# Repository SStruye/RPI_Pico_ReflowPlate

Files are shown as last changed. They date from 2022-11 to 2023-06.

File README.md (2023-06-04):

# PICO Reflow Plate v1
PICO Reflow Plate is a diy reflow plate based around a raspberry PI pico. The user is capable of adjusting the settings of the reflow curve like, preheat temperature, soak time, reflow temperature en reflow time.
## Usage:
- After  turning on the power the start menu will appear on the screen. 
- Selecting the setup menu will take you to the different adjustable parameters.
- After adjusting the parameters go back to the start menu en press start reflow. This will start te process.
- The current temperature, elapsed time and current state will be displayed on the screen during the reflow process.
- After the reflowing is done, the plate will go in to cooldown mode until the plate is below 50 degrees.

## Build:
### Hardware:
As casing I repurposed an old broken DC power supply.

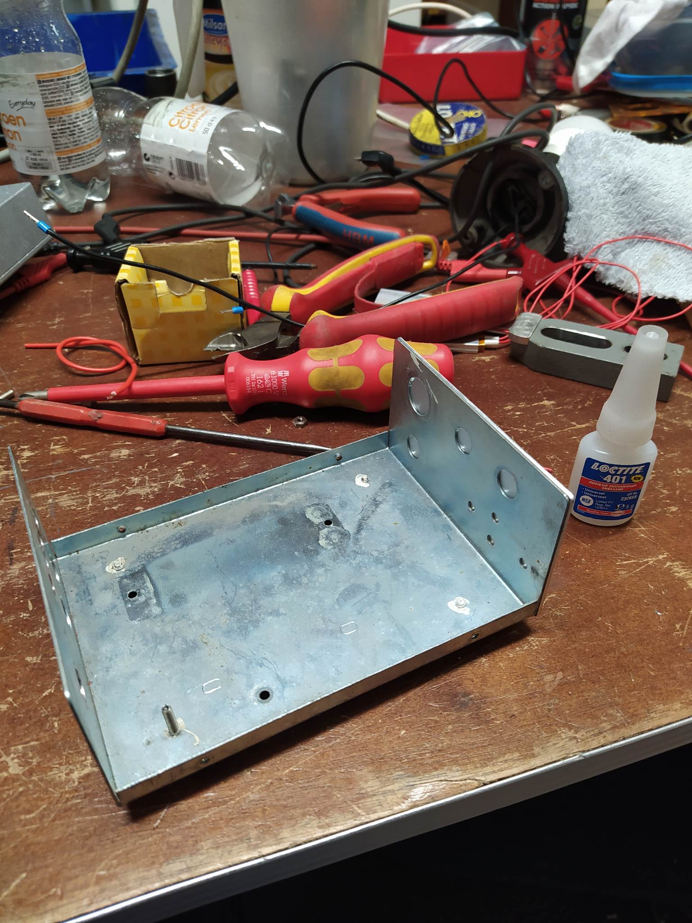
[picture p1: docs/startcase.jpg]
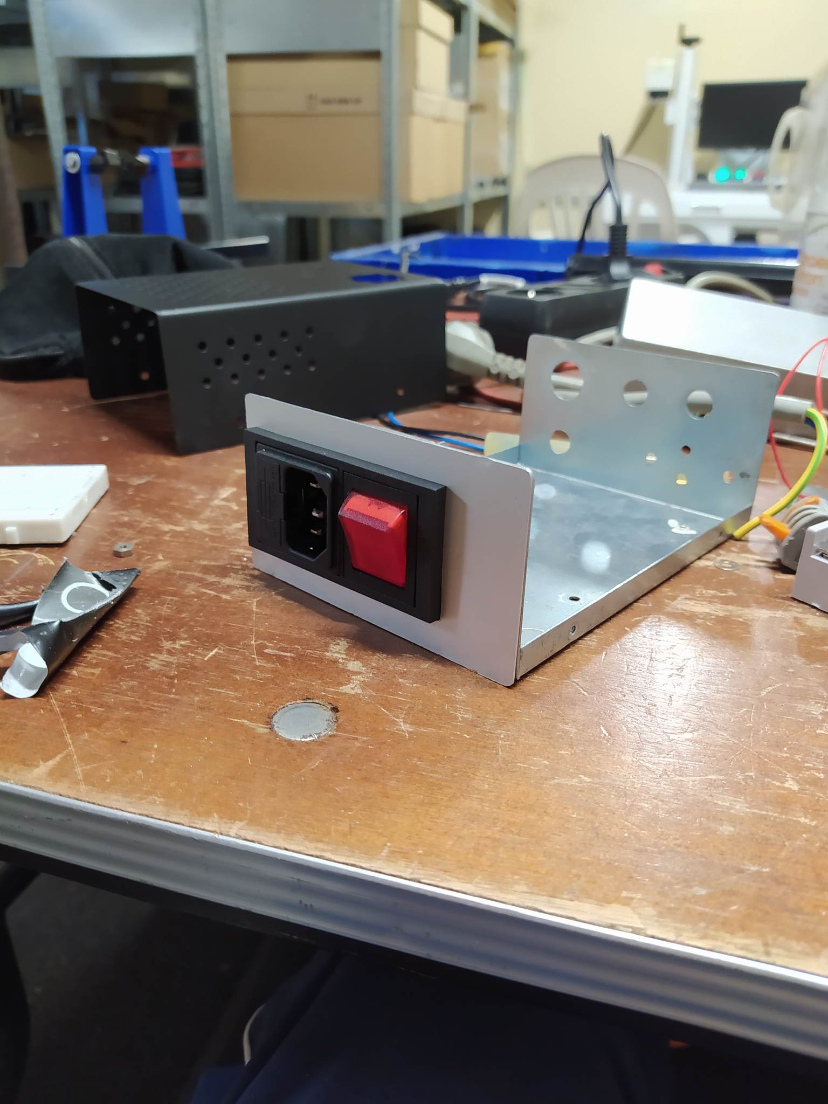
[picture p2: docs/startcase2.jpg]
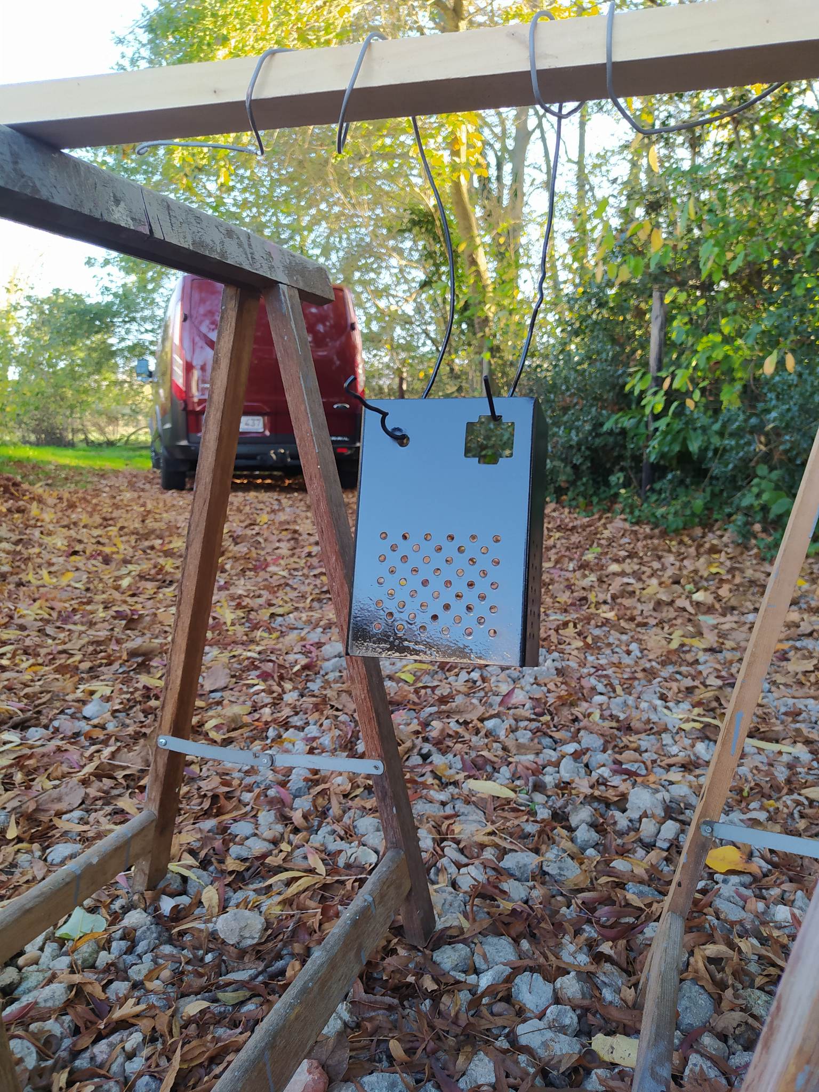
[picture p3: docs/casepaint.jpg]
  

As plate I used an 1590BB hammond enclosure where I used aluminum tape to position the NTC sensors, thermal paste to asure good thermal transfer and high heat silicone to keep everything in place.

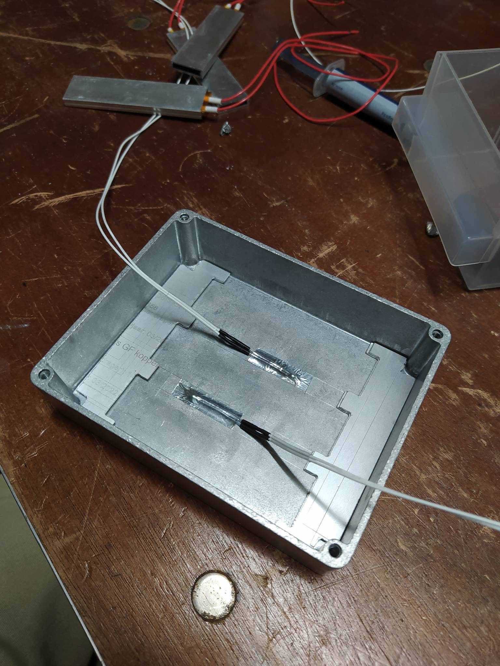
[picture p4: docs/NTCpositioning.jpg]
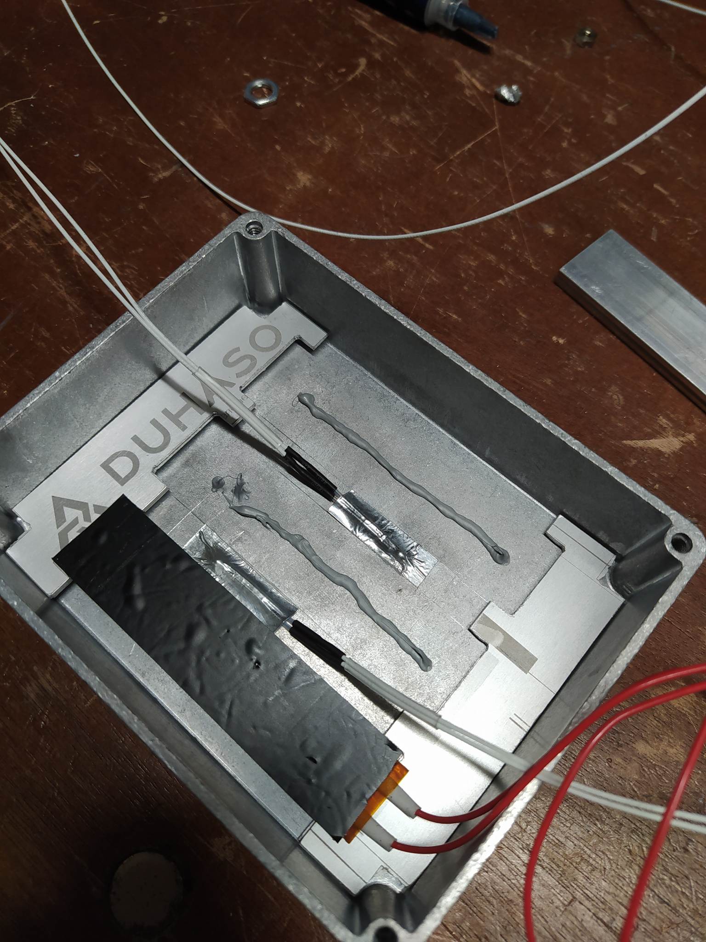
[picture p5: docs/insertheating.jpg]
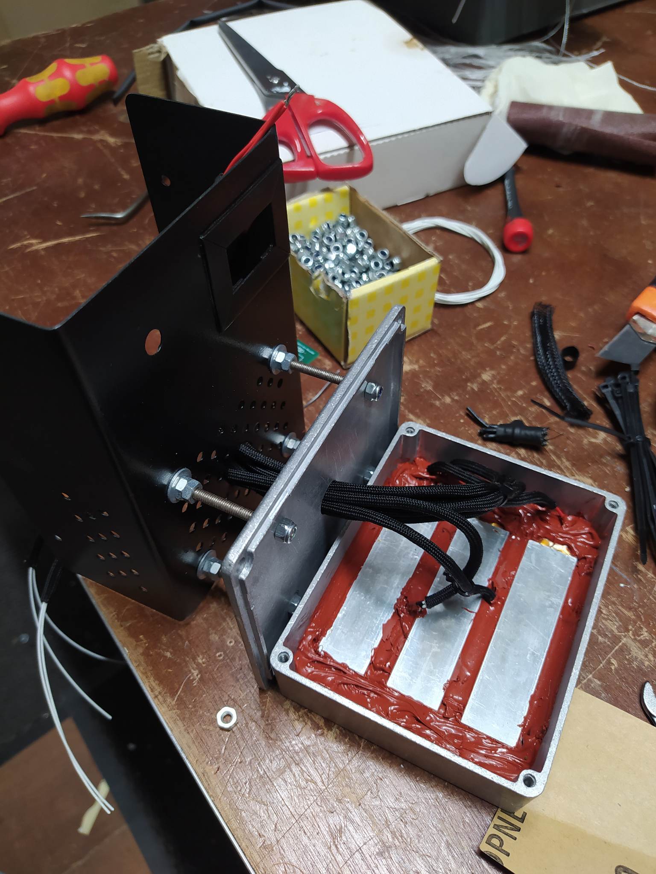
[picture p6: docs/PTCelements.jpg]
  

For ease of use, I made a pin distribution board for the PICO wich also holds the resistors for the led and the thermistors. The PCB was lasered on a fiber laser.

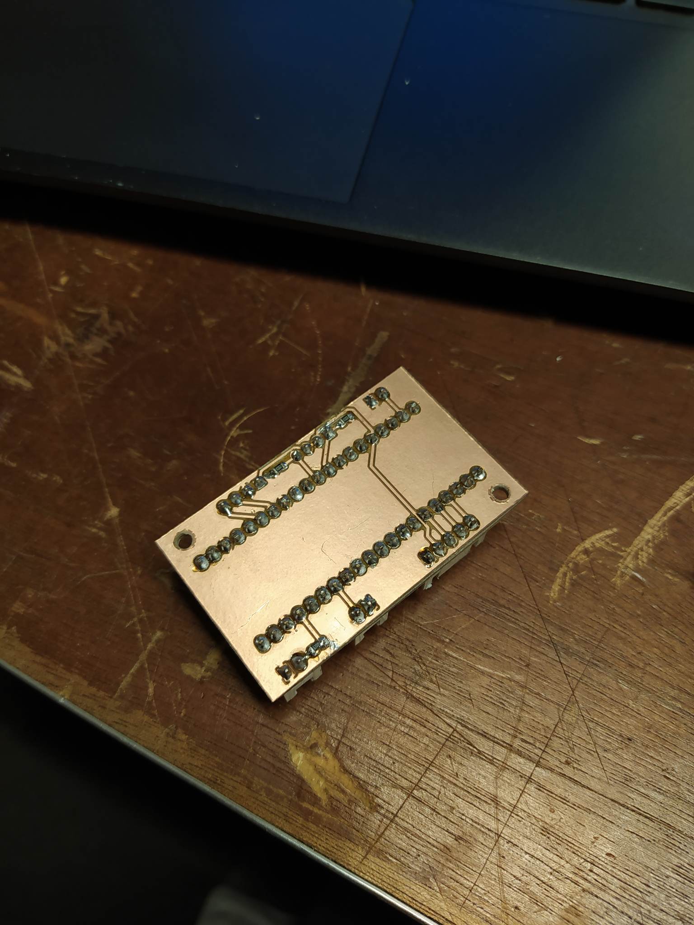
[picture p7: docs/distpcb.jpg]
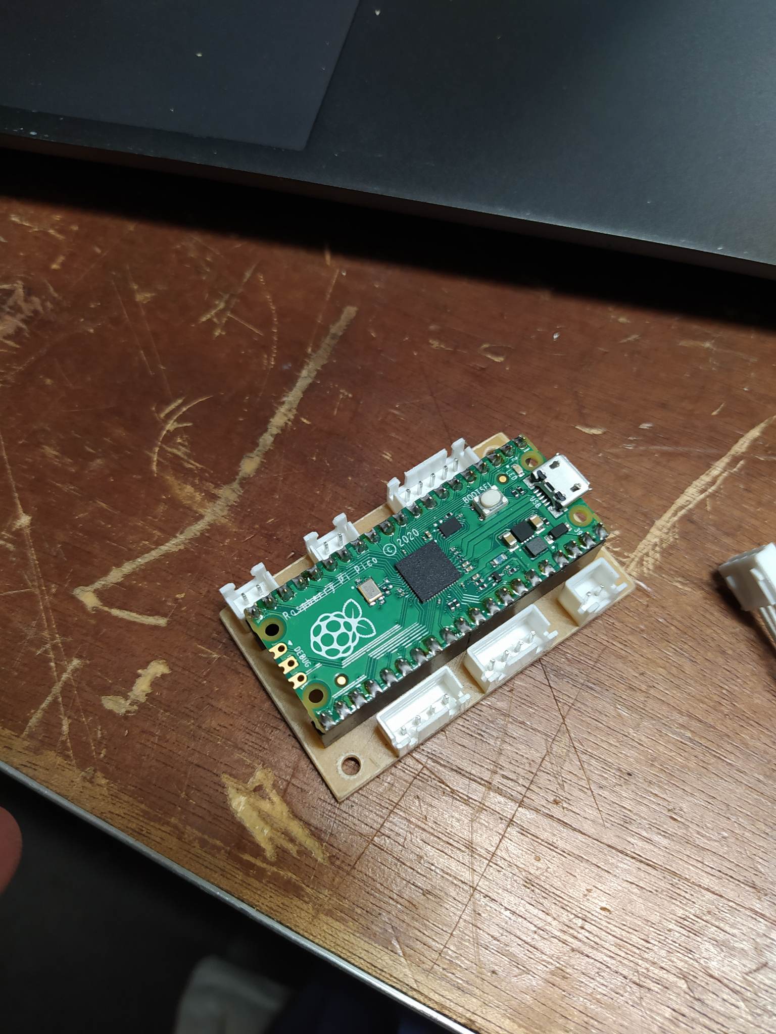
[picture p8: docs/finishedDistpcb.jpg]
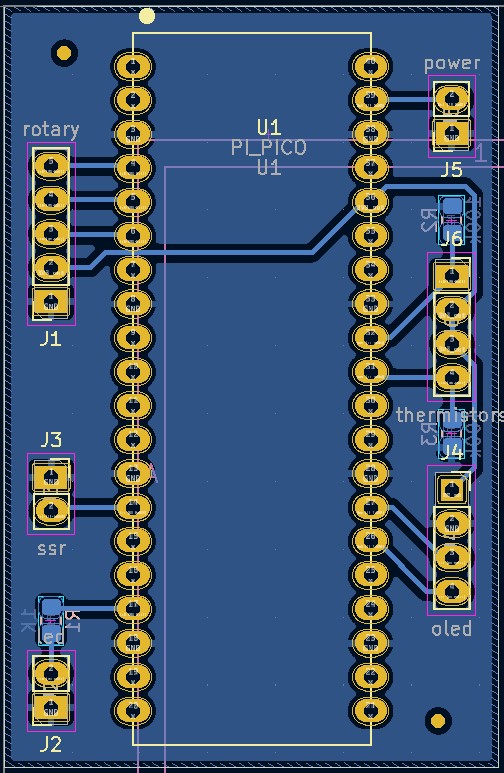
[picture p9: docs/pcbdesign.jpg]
  

Furthermore a solidstate relay is used to control the PTC elements, a 230V to 3.3V buck converter is used to power the PICO and an LED is added indicating when the hotplate is too hot too touch.
As user interface a SSD1306 display and a KY-040 rotary encoder with push button is used.

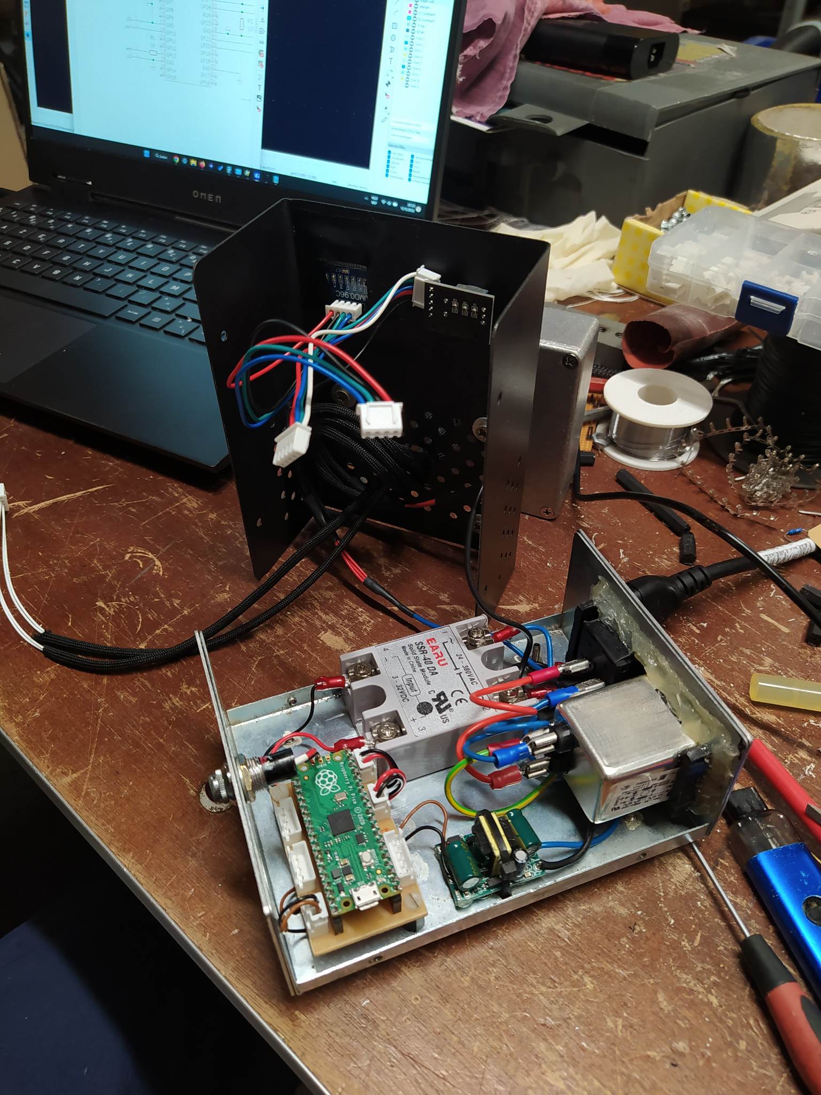
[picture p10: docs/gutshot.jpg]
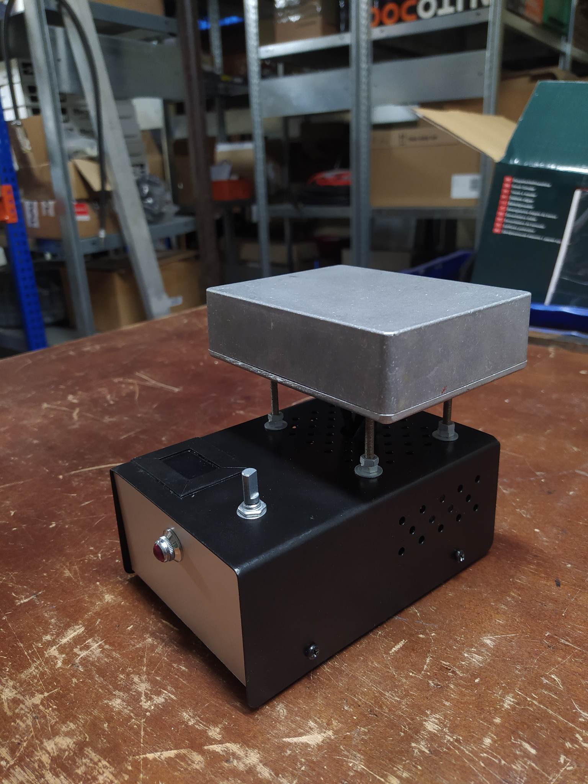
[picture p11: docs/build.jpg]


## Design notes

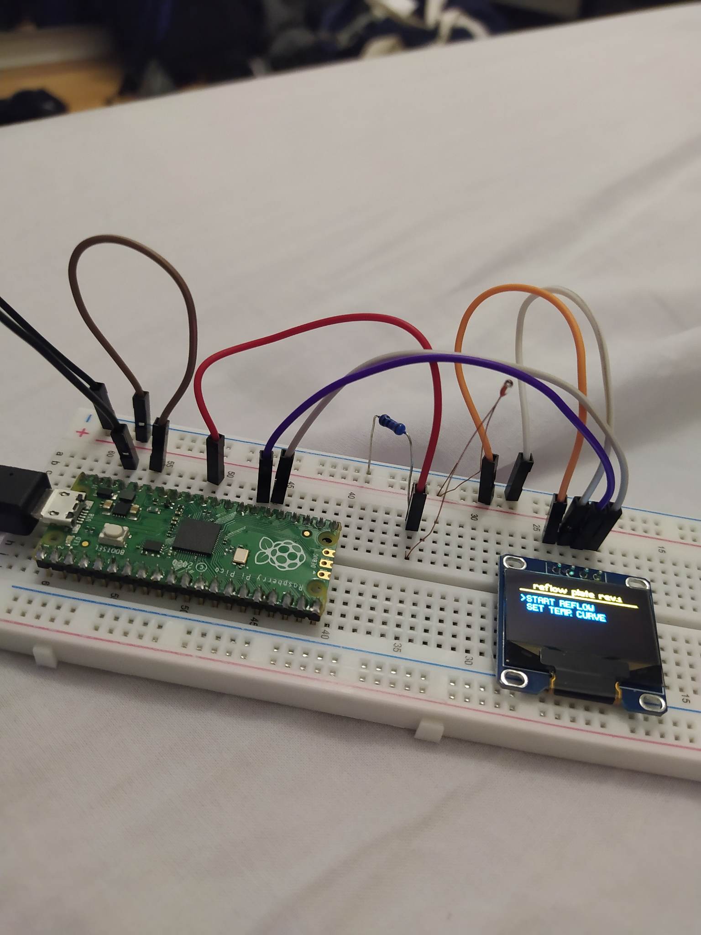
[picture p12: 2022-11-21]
docs/SSD1306.jpg

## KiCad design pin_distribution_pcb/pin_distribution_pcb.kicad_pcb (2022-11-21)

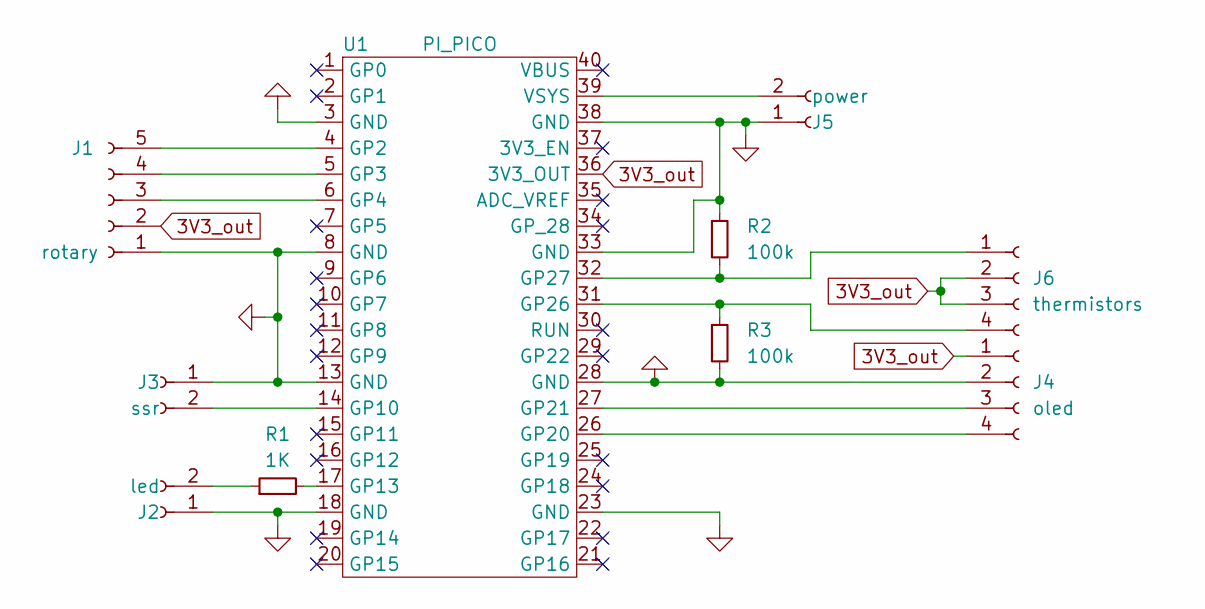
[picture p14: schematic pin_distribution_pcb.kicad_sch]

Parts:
J1: rotary; PinSocket_1x05_P2.54mm_Vertical
J2: led; PinSocket_1x02_P2.54mm_Vertical
J3: ssr; PinSocket_1x02_P2.54mm_Vertical
J4: oled; PinSocket_1x04_P2.54mm_Vertical
J5: power; PinSocket_1x02_P2.54mm_Vertical
J6: thermistors; PinSocket_1x04_P2.54mm_Vertical
R1: 1K; R_0805_2012Metric_Pad1.20x1.40mm_HandSolder
R2, R3: 100k; R_0805_2012Metric_Pad1.20x1.40mm_HandSolder
U1: PI_PICO

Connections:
3V3_out: J1.2, J4.1, J6.2, J6.3, U1.36 (3V3_OUT)
GND: J1.1, J2.1, J3.1, J4.2, J5.1, R2.1, R3.2, U1.3 (GND), U1.8 (GND), U1.13 (GND), U1.18 (GND), U1.23 (GND), U1.28 (GND), U1.33 (GND), U1.38 (GND)
unnamed: J5.2, U1.39 (VSYS)
unnamed: J6.1, R2.2, U1.32 (GP27)
unnamed: J6.4, R3.1, U1.31 (GP26)
unnamed: J2.2, R1.1
unnamed: R1.2, U1.17 (GP13)
unnamed: J1.5, U1.4 (GP2)
unnamed: J1.4, U1.5 (GP3)
unnamed: J1.3, U1.6 (GP4)
unnamed: J3.2, U1.14 (GP10)
unnamed: J4.4, U1.26 (GP20)
unnamed: J4.3, U1.27 (GP21)

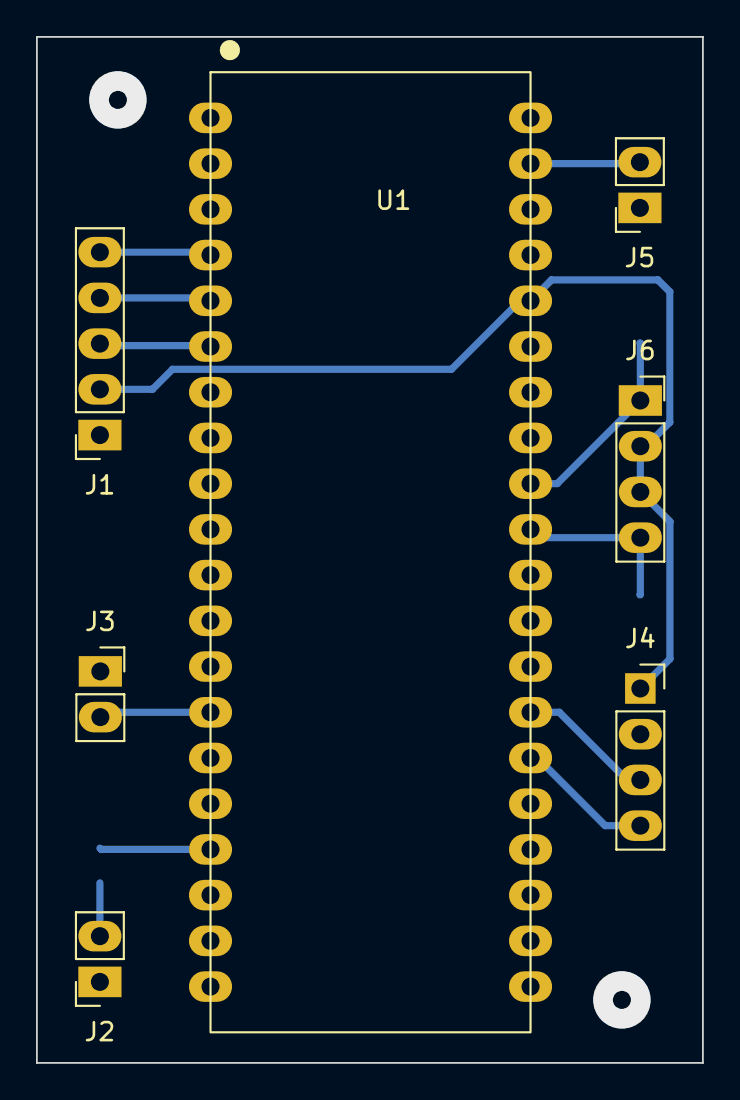
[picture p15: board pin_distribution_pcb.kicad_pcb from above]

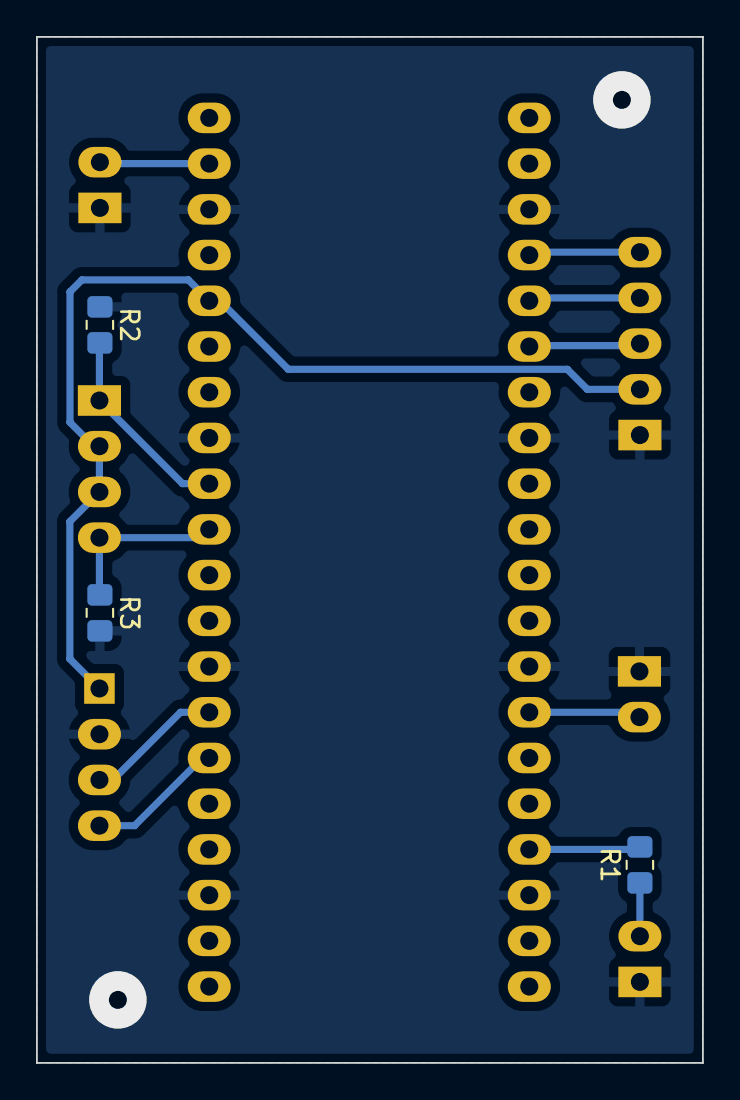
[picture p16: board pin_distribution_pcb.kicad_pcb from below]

Board: 2 copper layers, 37.0 x 57.0 mm, 10 parts (3 on the bottom side), 13 nets.

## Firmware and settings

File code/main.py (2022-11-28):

import machine
from machine import Pin
import time
from ui import Rotary
from FSM import Fsm

rotary = Rotary(3,2,4)
fsm = Fsm()

#force power supply in PWM mode (fixes false inputs from rotary caused by power supply noise)
Pin(23, Pin.IN).high()

action = 0

def rotary_changed(change):
    global action
    action = change
      
rotary.add_handler(rotary_changed)

while True:
    fsm.update(action)
    action = 0
    time.sleep(0.1)

            

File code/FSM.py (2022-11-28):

import machine
from PID import PID
from machine import Pin, PWM
import time
from ui import Gui
from thermistor import Thermistor

class FSM:    
    STATE 	= ['start',['setup','setStime','setStemp','setRtime','setRtemp'], ['preheat','soak','rampup','reflow'], 'cooldown']
   
    R_CW = 1
    R_CC = -1
    R_SW = 2
   
    sTIME	= 30
    sTEMP	= 100
    rTIME	= 30
    rTEMP	= 180
    cdTEMP	= 40
    
    def __init__(self):
        self.curr_state = 0
        self.position 	= 0
        self.curve		= [FSM.sTIME, FSM.sTEMP, FSM.rTIME, FSM.rTEMP]
               
        self.ntc 		= Thermistor(26, 27)
        self.curr_temp 	= 0
        
        self.gui 		= GUI(20, 21)
        
    def update_fsm(self, action):
        
        self.curr_temp = self.ntc.get_temp()
        
        if self.curr_temp >= FSM.cdTEMP:
            self.curr_state = FSM.STATE[3]
        
        if action == 0:
            if any(self.curr_state in i for i in FSM.STATE[:2]):		# No action	--> no update if state is menu or setup
                return 0
        
#START MENU
        if self.curr_state == FSM.STATE[0]:	                       
            if action == R_SW:						# if button	-> update state
                if self.position == 0:
                    self.curr_state = FSM.STATE[1][0]
                else:
                    self.curr_state = FSM.STATE[2][0]                                
            else:									# if rotate	-> update pos
                self.position + action
                if self.position > 1: self.position = 0
                if self.position < 0: self.position = 1
#SETUP MENU                
        elif self.curr_state == FSM.STATE[1][0]:
            if action == FSM.R_SW:					# if button	-> update state
                if self.position == 4:
                    self.curr_state = FSM.STATE[0]
                    self.position = 0
                else:
                    self.curr_state == FSM.STATE[1][self.position]
            else:									# if rotate	-> update pos
                self.position + action
                if self.position > 4: self.position = 0
                if self.position < 0: self.position = 4
#SET CURVE                
        elif self.curr_state == FSM.STATE[1][self.position]:
            if action == FSM.R_SW:					# if button	-> update state
                self.curr_state = FSM.STATE[0]
            else:									# if rotate	-> update curve value
                self.curve[self.position] += action
                gui.update_value(self.curr_state, self.curve[self.position])
'''PREHEAT'''           
        elif self.curr_state == FSM.STATE[2][0]:        
            #
'''SOAK'''
        elif self.curr_state == FSM.STATE[2][1]:
            #
'''RAMPUP'''
        elif self.curr_state == FSM.STATE[2][2]:
            #
'''REFLOW'''
        elif self.curr_state == FSM.STATE[2][3]:
            #
'''COOLDOWN'''
        elif self.curr_state == FSM.STATE[3]:
            if self.curr_temp <= FSM.cdTEMP:
                self.curr_state = FSM.STATE[0]
 
'''UPDATE FRAME'''
        gui.update_frame(self.curr_state, self.position, self.curve[self.position])
        return 0
            
        
            
            
        
    

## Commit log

2022-11-21 add gitignore + dist pcb file dump
    added gitignore for kicad files + file dump from distribution pcb design
    [pin_distribution_pcb.kicad_pcb, pin_distribution_pcb.kicad_sch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]
2022-11-28 code dump + flowchart
